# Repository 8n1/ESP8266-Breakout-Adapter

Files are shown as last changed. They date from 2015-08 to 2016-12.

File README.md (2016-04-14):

##ESP-07 & ESP-12 Breakout Adapter

###UPDATE [24.03.2016] - All Breakout Adapters are tested and working as expected. 
####Note: Documentations will be updated and completed within the next days.
<br />
####Version 1.1 - LM1117 (tested)
Used LDO: LM1117
Vin=4.8-15V, Dropout=1.2V, Iq=5mA

oshpark: https://oshpark.com/shared_projects/9CsYq2PY

####Version 2.0A - AS1363 (tested)
Used LDO: AS1363
Vin=3.5-5.5V, Dropout=150mV(-320mV), Iq=40µA

oshpark: https://oshpark.com/shared_projects/2IkxaFPm

####Version 2.0B - SPX3819 (tested)
Used LDO: SPX3819 
Vin=3.7-16V, Dropout=340mV(-550mV), Iq=90µA

oshpark: https://oshpark.com/shared_projects/jsl8ZcFp

####Version 3.1A - AS1363 - Mini (tested)
Used LDO: AS1363
Vin=3.5-5.5V, Dropout=150mV(-320mV), Iq=40µA

oshpark: https://oshpark.com/shared_projects/BgaX81QE

####Version 3.1B - SPX3819 - Mini (tested)
Used LDO: SPX3819 
Vin=3.7-16V, Dropout=340mV(-550mV), Iq=90µA

oshpark: https://oshpark.com/shared_projects/zpDg7761

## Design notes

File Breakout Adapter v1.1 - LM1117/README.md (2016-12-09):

## V1 - 1117 Adapter
<br />

### Changelog/Updates: <br />
V1.1 - Aug, 2015
- Silkscreen optimizations
- Bottom silkscreen moved from layer bNames to bPlace
- Added lables for bottom header
- Smaller gnd vias (0.02755906)

V1.0 - Jun, 2015
- First version

### Pictures
V1.0 - Bare PCB<br />
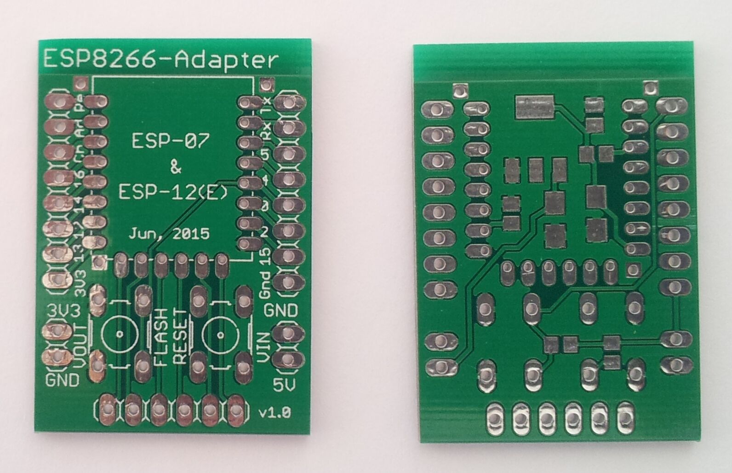
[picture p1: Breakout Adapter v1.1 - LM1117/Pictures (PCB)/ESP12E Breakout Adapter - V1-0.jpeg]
ESP-12 Breakout Adapter V1.0 - Bare PCB

<br />
V1.1 - OSH Park renderings<br />
ESP-12 Breakout Adapter V1.1 - Front&nbsp;
ESP-12 Breakout Adapter V1.1 - Back
<br />
#### Schematic
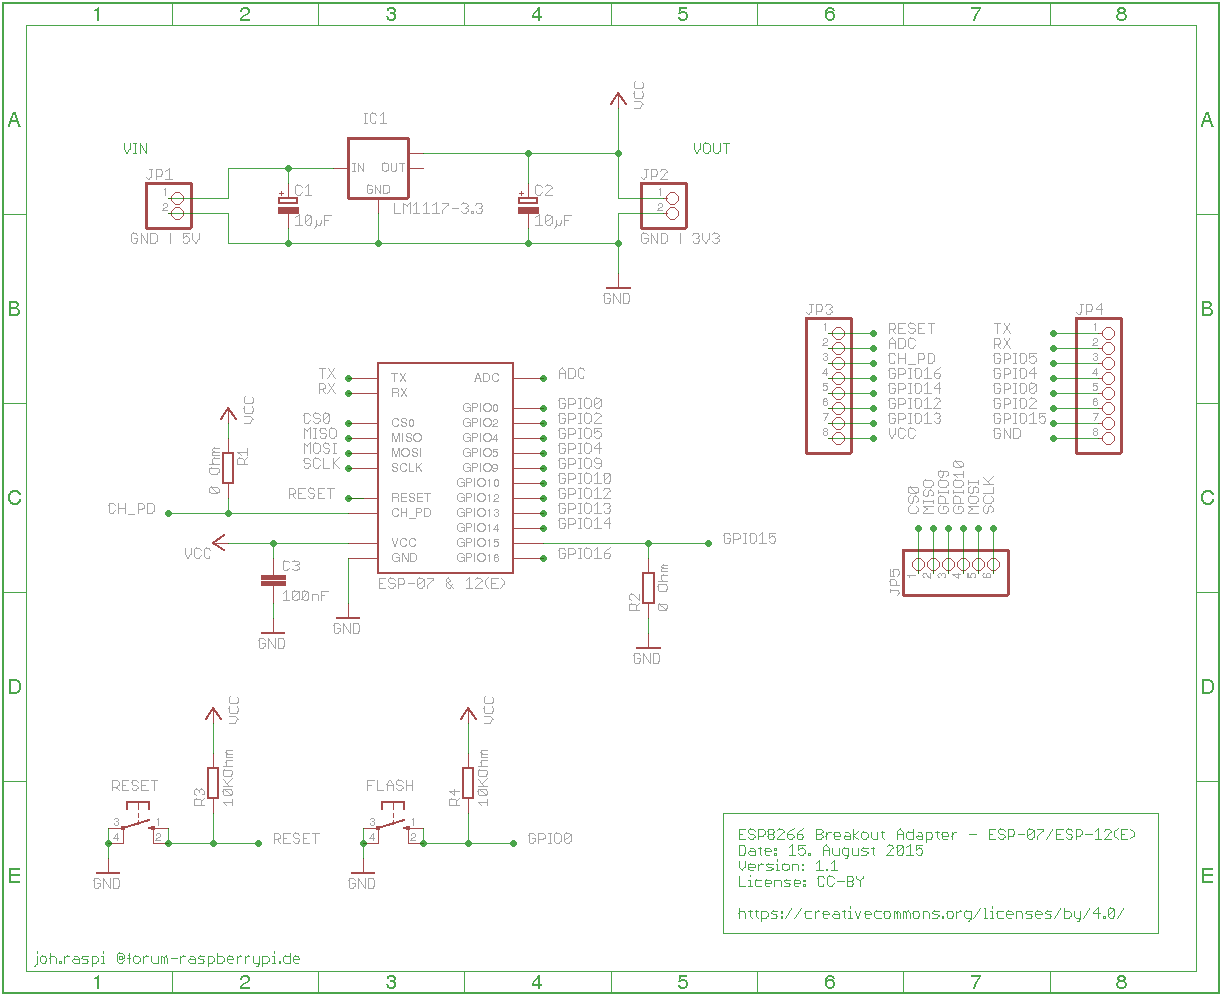
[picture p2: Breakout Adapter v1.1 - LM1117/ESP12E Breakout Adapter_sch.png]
ESP-12 Breakout Adapter V1.1 - Schematic


### Features
* LM1117 Voltage regulator (or pin compatible)
* Flash und Reset switch
* Pullup resistors for Reset, CH_PD and GPIO0
* Pulldown resistor for GPIO15
* ESP-12E bottom header brougth out (see note)
* Breadboard compatible -> One row on both sides stays free
* Except for the headers and switches, fully SMD

##### Note: The additional bottom header on the ESP-12E can not be used without modifying the ESP module:
http://www.esp8266.com/viewtopic.php?f=32&t=4094

### Partlist (v1.1)
| Part  | Value | Info |
|:---|:---|:---|
| IC1 | LM1117 or pincompatible | Voltage regulator |
| C1 | 10µF (Tantalum, Case B) | Input capacitor for IC1 (see the Datasheet)|
| C2 | 10µF (Tantalum, Case B) | Output capacitor for IC1 (see the Datasheet)|
| C3 | 100nF (Ceramic, 0805) | Decoupling capacitor for the ESP module |
| R1 | 10K (0805) * | Pullup resistor for CH_PD |
| R2 | 10K (0805) * | Pulldown resistor for GPIO15 |
| R3 | 10K (0805) | Pullup resistor for Reset |
| R4 | 10K (0805) | Pullup resistor for GPIO0 |
| SW1 | Tactile switch (4pin,6x6,THT) | Flash switch |
| SW2 | Tactile switch (4pin,6x6,THT) | Reset switch |

\* **or** 0Ohm resistor/solderbridge if pin is not needed

Note:  
Pullup and Pulldown resistors(R1, R2, R3, R4) should range from 4.7K to 10K.  
Output capacitor for the voltage regualtor(C2) should be a tantalum type. (See the datasheet)

Pinheader
* 2x 1x8 (2.54mm)
* 2x 1x2 (2.54mm)
* (1x 1x6  (2.54mm)) - "E header"
<br />
Optional "socket" for the esp module
* 2x 1x8 (2mm)
* (1x 1x6 (2mm)) - "E header"

#### Resources:
- LM1117 Datasheet - http://www.ti.com/lit/ds/symlink/lm1117-n.pdf
- AMS1117 Datasheet - http://www.advanced-monolithic.com/pdf/ds1117.pdf

- More Pictures - http://imgur.com/a/fsVE8 (imgur album)

#### This adapter on OSH Park:
- ESP8266 Breakout v1.1 - https://oshpark.com/shared_projects/9CsYq2PY

#### License
<br />
Creative Commons Attribution 4.0 International<br />
http://creativecommons.org/licenses/by/4.0/

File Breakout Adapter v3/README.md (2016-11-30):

## V3 - Mini Adapter

### Changelog/Updates: <br />

V3.1 - Nov, 2015
- Footprint for VREG input and output capacitors changed from 1206 to 0805
- VREG bypass capacitor (C3) removed
- Bigger solderpads for the tactile switches
- Pullup resistor for GPIO2 added (R7)
- Part numbers on bottom side replaced with actual values
- Layout optimized
- Silkscreen fix (description of where the led is connected to was swapped: 3V3<->GPIO13)

V3.0 - Okt, 2015
- First version

### Pictures
V3.1B - OSH Park renderings<br />
ESP-12 Breakout Adapter V1.1 - Front&nbsp;
ESP-12 Breakout Adapter V1.1 - Back
<br />
### Schematic
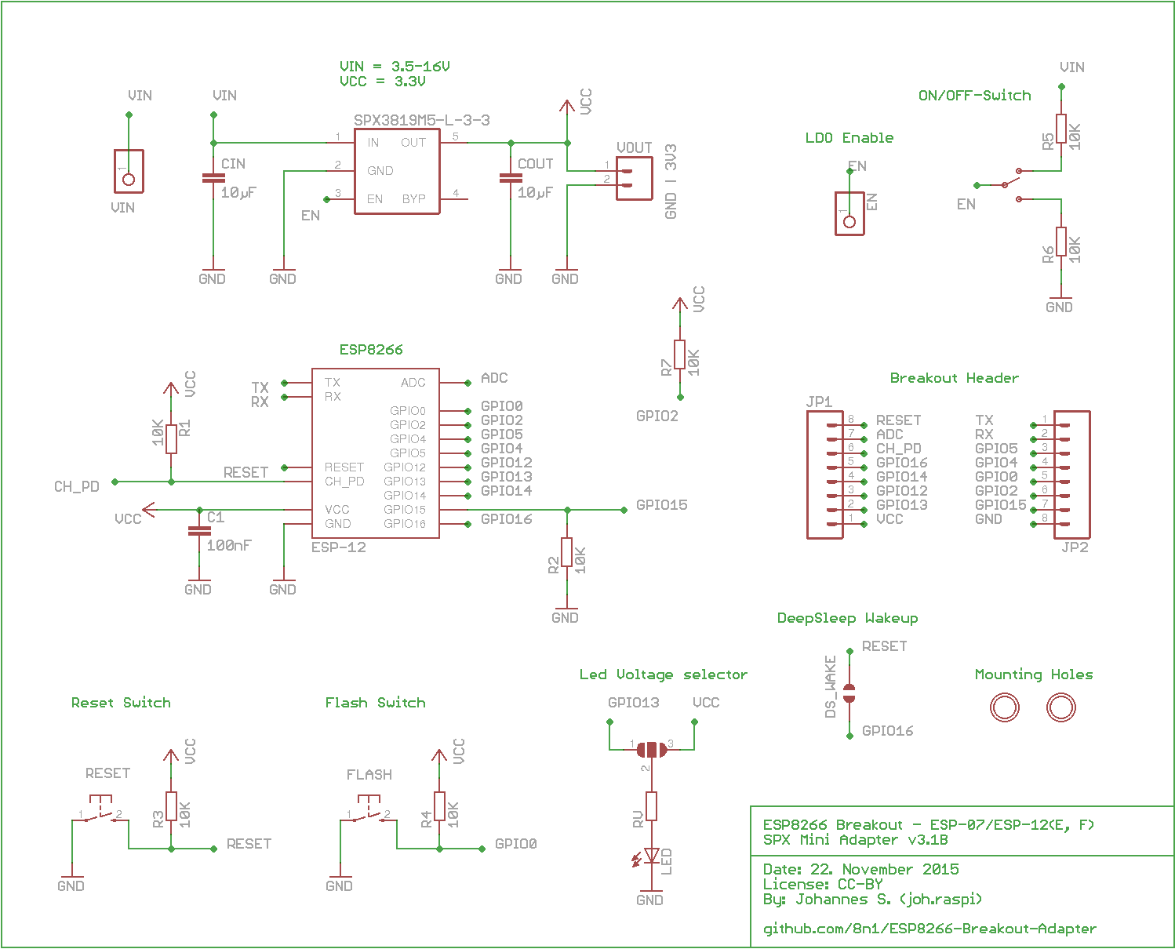
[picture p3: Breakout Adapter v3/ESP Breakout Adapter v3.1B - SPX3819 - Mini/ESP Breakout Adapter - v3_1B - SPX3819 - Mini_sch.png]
ESP-12 Breakout Adapter V3.1 - Schematic


### Features
* ESP-07, ESP-12, ESP-12E and ESP-12F compatible (bottom header for E and F module is not brought out)
* On-board voltage regulator
* Flash and Reset switch
* Pullup resistors for Reset, CH_PD, GPIO0 and GPIO2
* Pulldown resistor for GPIO15
* On/Off Switch *
* LDO Enable Pin brougth out **
* DeepSleep wake-up jumper - Connects Pin8 and Pin32 and allows automatic deep-sleep wake-up
* On-board LED - Anode(+) can either be connected to the LDO ouptut ("3V3") or to "GPIO13" (selected using solderjumper)
* 2 Mountingholes (2.0mm)*)
* Expect for the headers fully SMD
* Breadboard compatible -> 3 rows stay free
* Very small

\* Can be used to completly shutdown the board and everything connected to it. The current consumption in this state will typically be &lt;1µA.  
\** Can be used to externaly turn the board on if the On/Off switch is set to "Off", or off if the On/Off switch is set to "On".

### Partlist (v3.1)
| Part  | Value | Info |
|:---|:---|:---|
| IC1 | AS1363-BSTT-33 (SOT23-6)  | Voltage regulator - Variant "A" |
| IC1 | SPX3819M5-L-3-3 (SOT23-5) | Voltage regulator - Variant "B" |
| C1 | 10µF (Ceramic, 0805) | Input capacitor for the voltage regulator |
| C2 | 10µF (Ceramic, 0805) | Output capacitor for the voltage regulator |
| C3 | 100nF (Ceramic, 0805) | Decoupling capacitor for the ESP module |
| R1 | 10K (0805) * | Pullup resistor for CH_PD |
| R2 | 10K (0805) * | Pulldown resistor for GPIO15 |
| R3 | 10K (0805) | Pullup resistor for Reset |
| R4 | 10K (0805) | Pullup resistor for GPIO0 |
| R7 | 10K (0805) | Pullup resistor for GPIO2 |
| R5 | 10K (0805) | Pullup for LDO enable pin |
| R6 | 10K (0805) | Pulldown for LDO enable pin |
| RV | ~220 Ohm (0805) | [Optional] Current limiting resistor for the led ** |
| LED | LED (0805) ** | [Optional] Led of choice |
| DS | Solderbridge | DeepSleep wake-up jumper |
| FLASH | Tactile Pushbutton SMD 2pin 6x3 | Flash button |
| RESET | Tactile Pushbutton SMD 2pin 6x3 | Reset button |
| On/Off | SMD slide switch (DK: CKN10374CT-ND) (<a href="http://www.ebay.at/itm/20PCS-Mini-Slide-Power-Off-On-Panel-PCB-MINI-SMD-Solder-Switch-SPM-/120731615109">ebay</a>) | On/Off switch |

\* **or** 0Ohm resistor/solderbridge if pin is not needed<br /> 
\** if the led is connected to GPIO13 the led current must be lower then 12mA, calculate the resister value accordingly!

Note:  
Pullup and Pulldown resistors(**R1, R2, R3, R4, R7**)  can range from 4.7K to 10K.  
Pullup and Pulldown resistor for the LDO enable pin(**R5, R6**) should be 10K or higher (100K max).  
Input and output capacitors for the voltage regualtor(**C1, C2**) are LOW ESR ceramic types. (I'm using: SAMSUNG CL21A106KOQNNNG)  

Pinheader
* 2x 1x10 (2.54mm)

Optional "socket" header for the esp module
* 2x 1x8 (2mm) female and male pin header

### Difference between variant A and B
The only difference is the used LDO. Variant A uses the AS1363, variant B the SPX3819(or pincompatible).

#### Resources:
- AS1363 Datasheet - https://ams.com/eng/content/download/1961/15107/file/AS1364_Datasheet_EN_v3.pdf
- SPX3819 Datasheet - https://www.adafruit.com/datasheets/SPX3819_DS_R202_052014.pdf

- More Pictures V3.1 - http://imgur.com/a/jSkG7 (imgur album)
- More Pictures V3.0 - http://imgur.com/a/w46x3 (imgur album)

#### This adapter on OSH Park:
- ESP8266 Breakout v3.1A - https://oshpark.com/shared_projects/RfAN6raq
- ESP8266 Breakout v3.1B - https://oshpark.com/shared_projects/OPku1n9U

#### License
<br />
Creative Commons Attribution 4.0 International<br />
http://creativecommons.org/licenses/by/4.0/

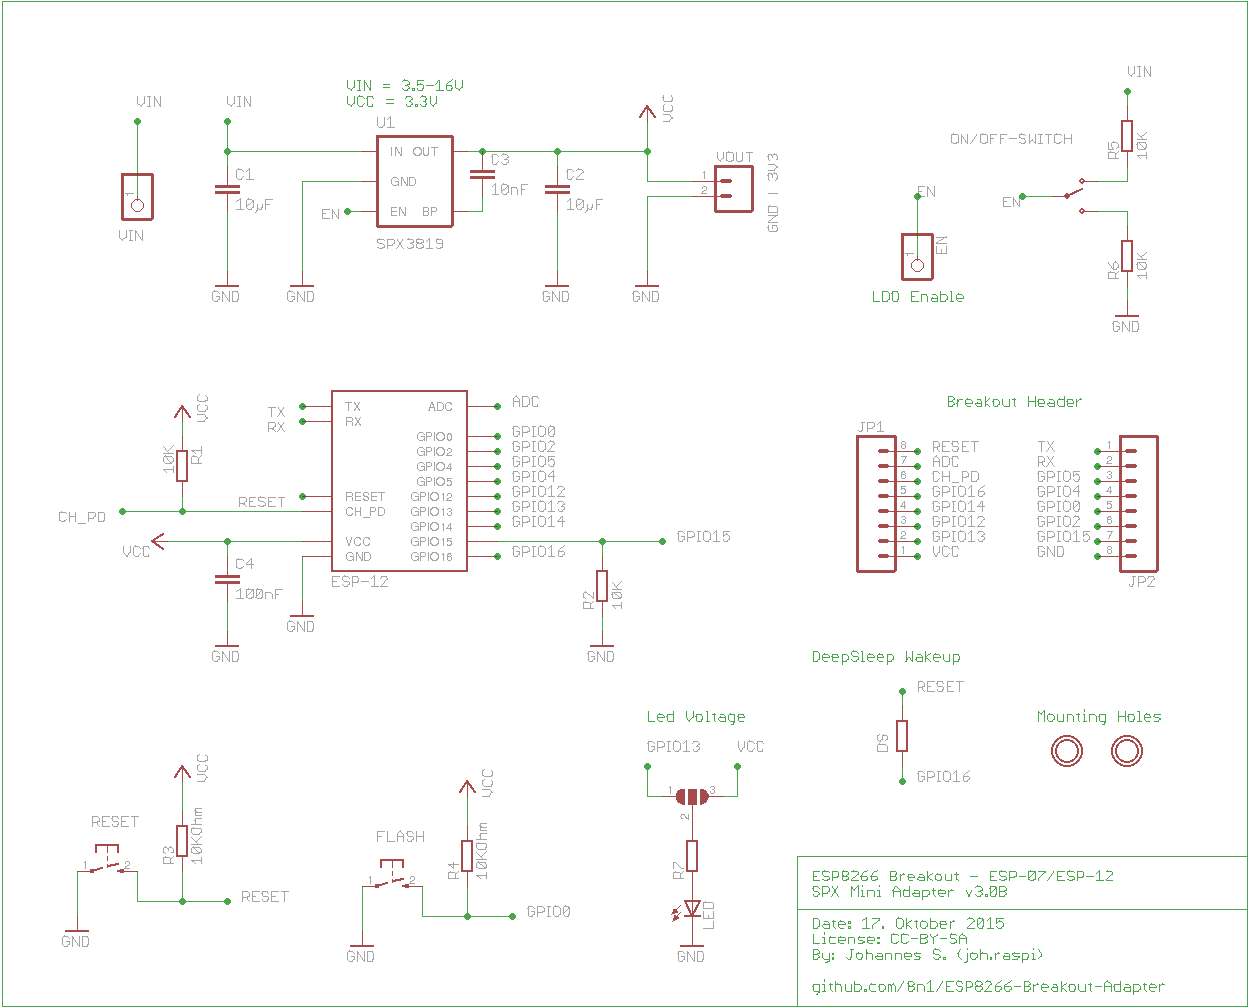
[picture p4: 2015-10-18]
Breakout Adapter v3/ESP Breakout Adapter v3.0B - SPX3819 - Mini/ESP Breakout Adapter - v3_0B - SPX3819 - Mini_sch.png

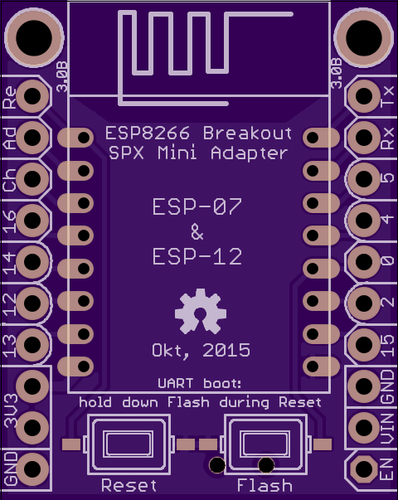
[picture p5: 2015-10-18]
Breakout Adapter v3/ESP Breakout Adapter v3.0B - SPX3819 - Mini/oshpark renderings/oshpark - board top.png

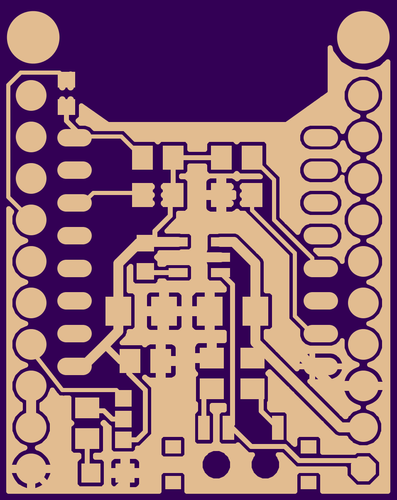
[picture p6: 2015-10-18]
Breakout Adapter v3/ESP Breakout Adapter v3.0B - SPX3819 - Mini/oshpark renderings/oshpark - bottom layer.png

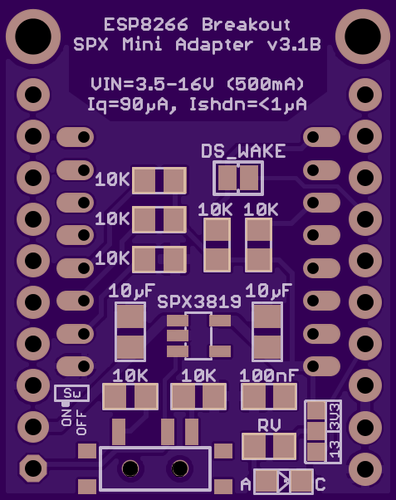
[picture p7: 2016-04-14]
Breakout Adapter v3/ESP Breakout Adapter v3.1B - SPX3819 - Mini/oshpark renderings/Board_Bottom.png

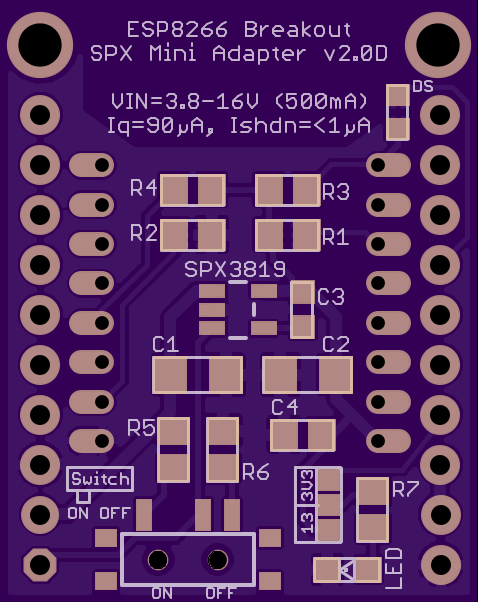
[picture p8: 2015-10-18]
Breakout Adapter v3/ESP Breakout Adapter v3.0B - SPX3819 - Mini/oshpark renderings/b_oshpark - board bottom_b.png

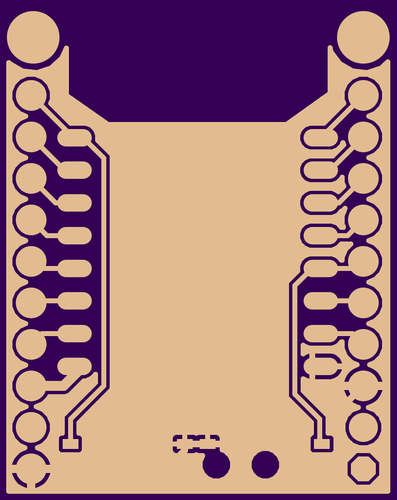
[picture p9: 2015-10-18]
Breakout Adapter v3/ESP Breakout Adapter v3.0A - AS1363 - Mini/oshpark renderings/oshpark - top layer.png

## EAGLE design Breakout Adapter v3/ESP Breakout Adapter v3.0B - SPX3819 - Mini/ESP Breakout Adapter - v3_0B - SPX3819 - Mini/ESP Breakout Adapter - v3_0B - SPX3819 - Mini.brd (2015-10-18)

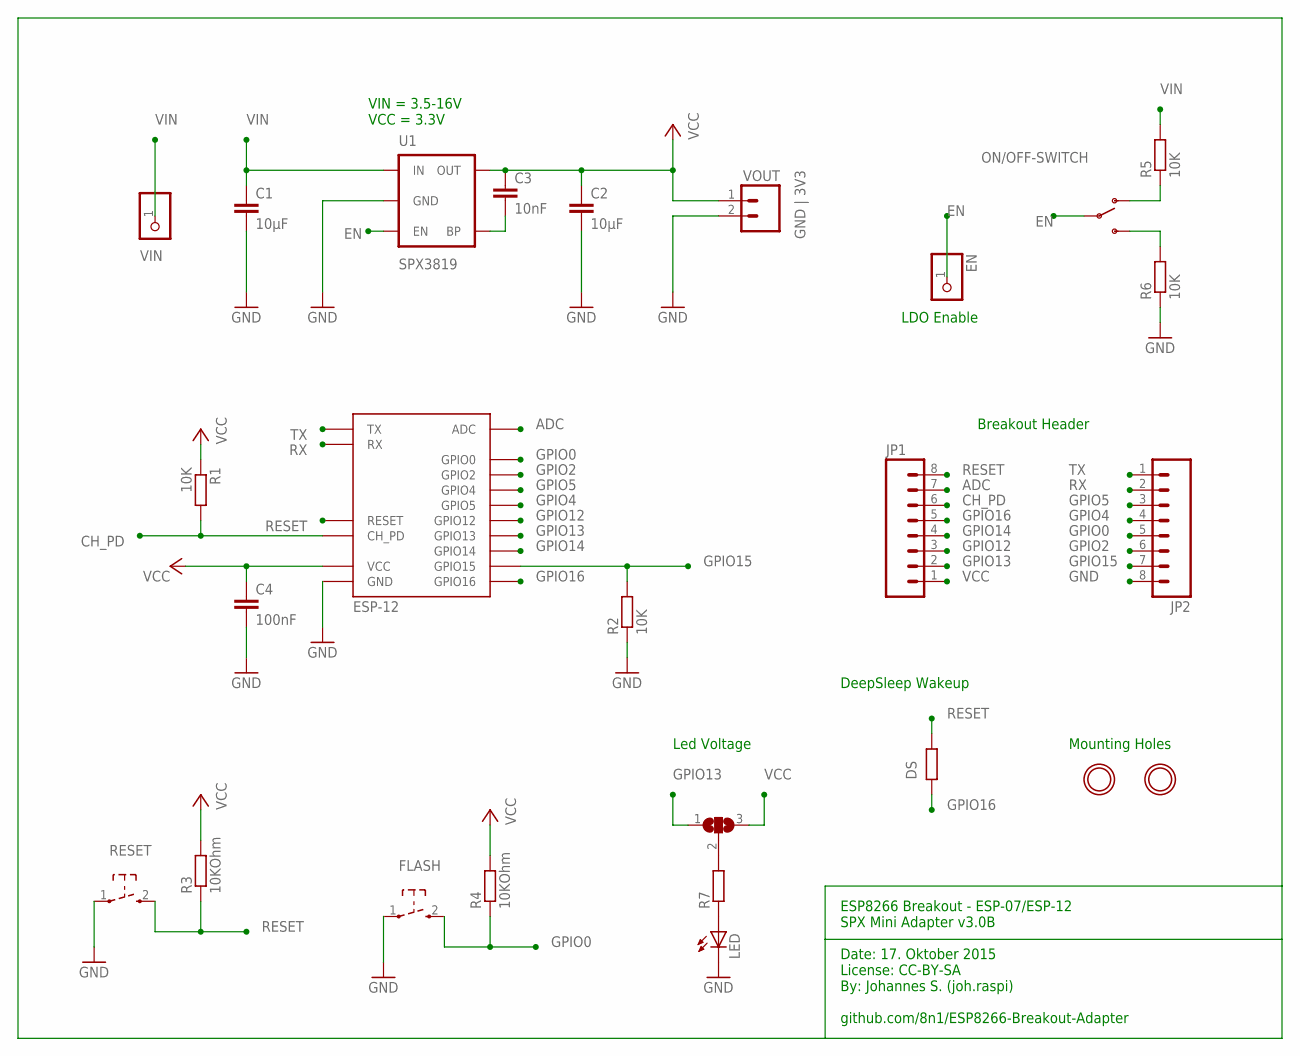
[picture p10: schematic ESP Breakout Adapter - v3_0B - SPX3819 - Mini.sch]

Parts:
C1, C2: 10µF; C1206
C3: 10nF; C0603K
C4: 100nF; C0805
DS: R-EU_R0603; R0603
EN: PINHD-1X1; 1X01
FLASH: SW_TACT_2P-3X6; SW_TACT_3X6
JP1, JP2: M081X08; 1X08
LED: LEDCHIPLED_0805; CHIPLED_0805
LED_VOLTAGE: SJ2W; SJ_2
ON/OFF-SWITCH: SWITCH_SPDT; KPS-1290
R1, R2, R5, R6: 10K; R0805
R3, R4: 10KOhm; R0805
R7: R-EU_R0805; R0805
RESET: SW_TACT_2P-3X6; SW_TACT_3X6
U1: SPX3819; SOT23-5
U$1: ESP-12
U$4, U$5: MOUNTINGHOLE2.0; MOUNTINGHOLE_2.0_PLATED
VIN: M01PTH_2MM; 1X01-CLEANBIG
VOUT: GND | 3V3; 1X02

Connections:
123: ON/OFF-SWITCH.S, R6.2
ADC: JP1.7, U$1.ADC
CH_PD: JP1.6, R1.2, U$1.CH_PD
EN: EN.1, ON/OFF-SWITCH.P, U1.3 (EN)
GND: C1.2, C2.2, C4.2, FLASH.1, JP2.8, LED.C, R2.1, R6.1, RESET.1, U1.2 (GND), U$1.GND, VOUT.2
GPIO0: FLASH.2 (3), JP2.5, R4.1, U$1.GPIO0
GPIO2: JP2.6, U$1.GPIO2
GPIO4: JP2.4, U$1.GPIO5
GPIO5: JP2.3, U$1.GPIO4
GPIO12: JP1.3, U$1.GPIO12
GPIO13: JP1.2, LED_VOLTAGE.1, U$1.GPIO13
GPIO14: JP1.4, U$1.GPIO14
GPIO15: JP2.7, R2.2, U$1.GPIO15
GPIO16: DS.1, JP1.5, U$1.GPIO16
unnamed: LED_VOLTAGE.2, R7.2
unnamed: ON/OFF-SWITCH.O, R5.1
unnamed: LED.A, R7.1
RESET: DS.2, JP1.8, R3.1, RESET.2 (3), U$1.RESET
RX: JP2.2, U$1.RX
SET/BYP: C3.2, U1.4 (BP)
TX: JP2.1, U$1.TX
VCC: C2.1, C3.1, C4.1, JP1.1, LED_VOLTAGE.3, R1.1, R3.2, R4.2, U1.5 (OUT), U$1.VCC, VOUT.1
VIN: C1.1, R5.2, U1.1 (IN), VIN.1

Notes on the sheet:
ESP8266 Breakout - ESP-07/ESP-12 SPX Mini Adapter v3.0B Date: 17. Oktober 2015 License: CC-BY-SA By: Johannes S. (joh.raspi) github.com/8n1/ESP8266-Breakout-Adapter
Mounting Holes
DeepSleep Wakeup
Breakout Header
VIN = 3.5-16V VCC = 3.3V
Led Voltage
LDO Enable

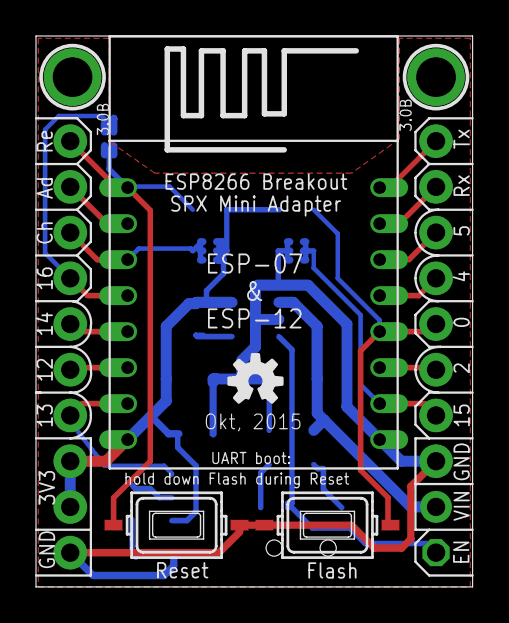
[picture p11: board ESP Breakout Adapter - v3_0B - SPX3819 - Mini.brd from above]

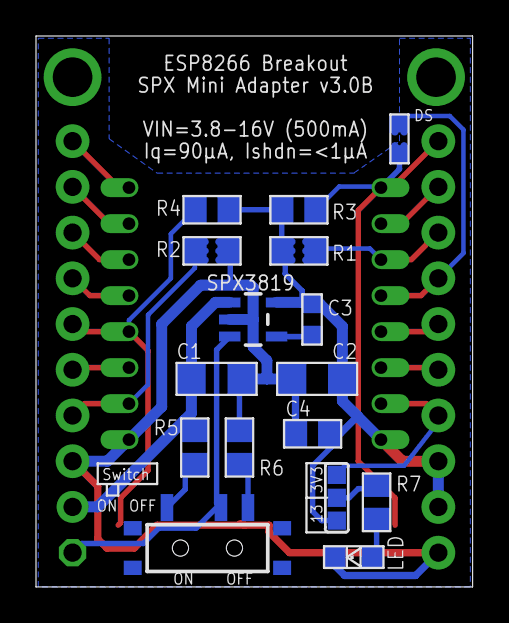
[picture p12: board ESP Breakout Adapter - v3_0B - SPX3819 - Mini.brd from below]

Board: 2 copper layers, 24.3 x 30.6 mm, 27 parts (16 on the bottom side), 23 nets.

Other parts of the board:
U$2: OSHW-LOGO-S

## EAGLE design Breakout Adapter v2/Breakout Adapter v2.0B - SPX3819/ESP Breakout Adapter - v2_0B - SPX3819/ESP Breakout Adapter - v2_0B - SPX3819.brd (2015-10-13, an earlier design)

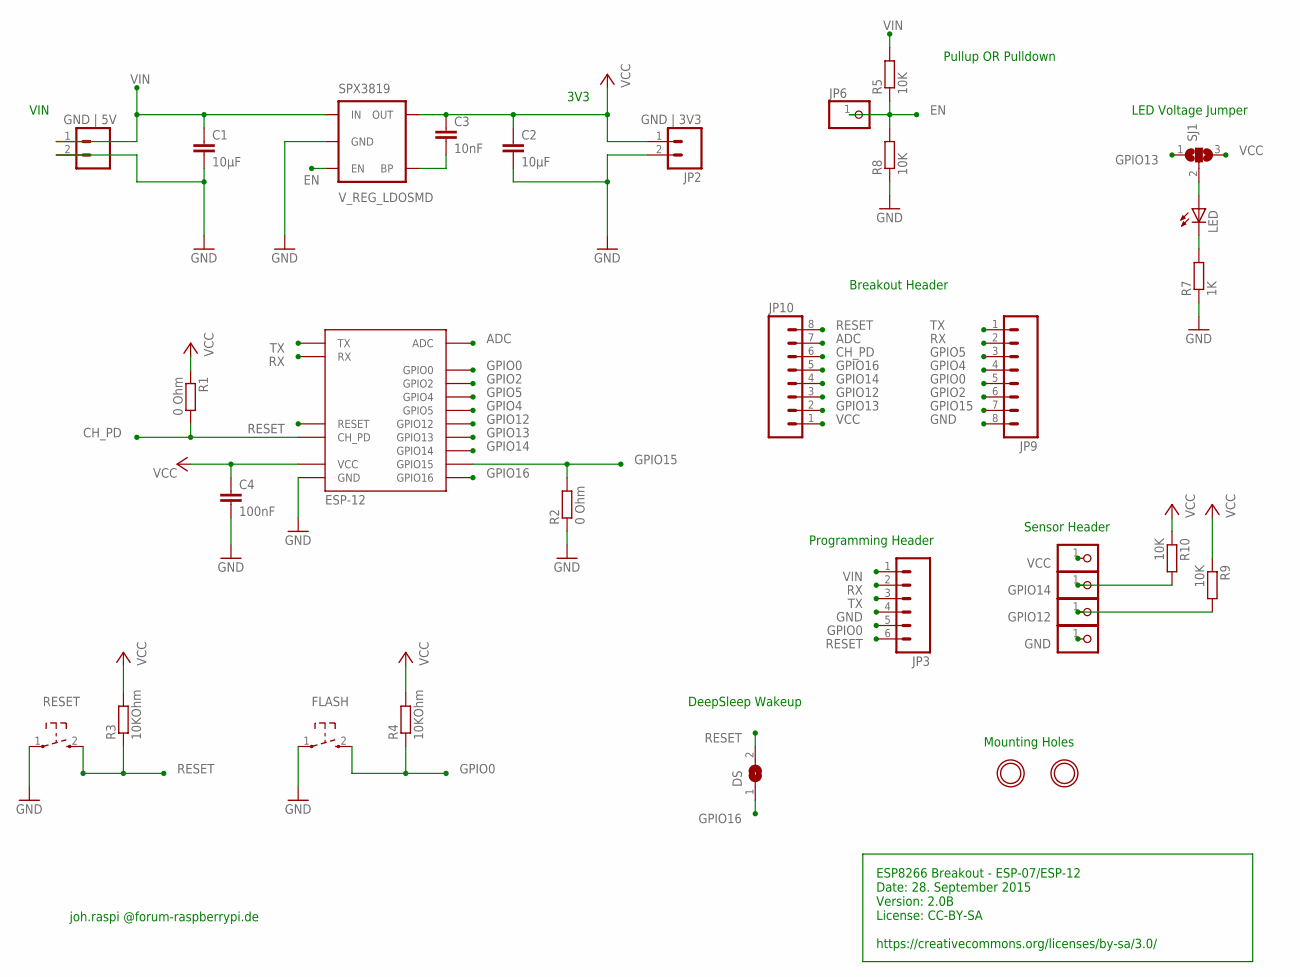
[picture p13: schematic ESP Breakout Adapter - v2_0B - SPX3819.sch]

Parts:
C1, C2: 10µF; C1206
C3: 10nF; C0603K
C4: 100nF; C0805
DS: SJ
FLASH: SW_TACT_2P-3X6; SW_TACT_3X6
JP1: GND | 5V; 1X02
JP2: GND | 3V3; 1X02
JP3: M06SIP; 1X06
JP4, JP6, JP7, JP8, JP11: PINHD-1X1; 1X01
JP9, JP10: M081X08; 1X08
LED: LED-0805; LED-805
R1, R2: 0 Ohm; R0805
R3, R4: 10KOhm; R0805
R5, R8, R9, R10: 10K; R0805
R7: 1K; R0805
RESET: SW_TACT_2P-3X6; SW_TACT_3X6
SJ1: SJ2W; SJ_2
SPX3819: V_REG_LDOSMD; SOT23-5
U$1: ESP-12
U$4, U$5: MOUNTINGHOLE2.0; MOUNTINGHOLE_2.0_PLATED

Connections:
ADC: JP10.7, U$1.ADC
CH_PD: JP10.6, R1.2, U$1.CH_PD
EN: JP6.1, R5.1, R8.2, SPX3819.3 (EN)
GND: C1.2, C2.2, C4.2, FLASH.1, JP1.2, JP2.2, JP3.4, JP4.1, JP9.8, R2.1, R7.1, R8.1, RESET.1, SPX3819.2 (GND), U$1.GND
GPIO0: FLASH.2 (3), JP3.5, JP9.5, R4.1, U$1.GPIO0
GPIO2: JP9.6, U$1.GPIO2
GPIO4: JP9.4, U$1.GPIO5
GPIO5: JP9.3, U$1.GPIO4
GPIO12: JP7.1, JP10.3, R9.2, U$1.GPIO12
GPIO13: JP10.2, SJ1.1, U$1.GPIO13
GPIO14: JP10.4, JP11.1, R10.2, U$1.GPIO14
GPIO15: JP9.7, R2.2, U$1.GPIO15
GPIO16: DS.1, JP10.5, U$1.GPIO16
unnamed: LED.C, R7.2
unnamed: LED.A, SJ1.2
RESET: DS.2, JP3.6, JP10.8, R3.1, RESET.2 (3), U$1.RESET
RX: JP3.2, JP9.2, U$1.RX
SET/BYP: C3.2, SPX3819.4 (BP)
TX: JP3.3, JP9.1, U$1.TX
VCC: C2.1, C3.1, C4.1, JP2.1, JP8.1, JP10.1, R1.1, R3.2, R4.2, R9.1, R10.1, SJ1.3, SPX3819.5 (OUT), U$1.VCC
VIN: C1.1, JP1.1, JP3.1, R5.2, SPX3819.1 (IN)

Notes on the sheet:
VIN
3V3
ESP8266 Breakout - ESP-07/ESP-12 Date: 28. September 2015 Version: 2.0B License: CC-BY-SA https://creativecommons.org/licenses/by-sa/3.0/
joh.raspi @forum-raspberrypi.de
Mounting Holes
Pullup OR Pulldown
DeepSleep Wakeup
Programming Header
Sensor Header
Breakout Header
LED Voltage Jumper

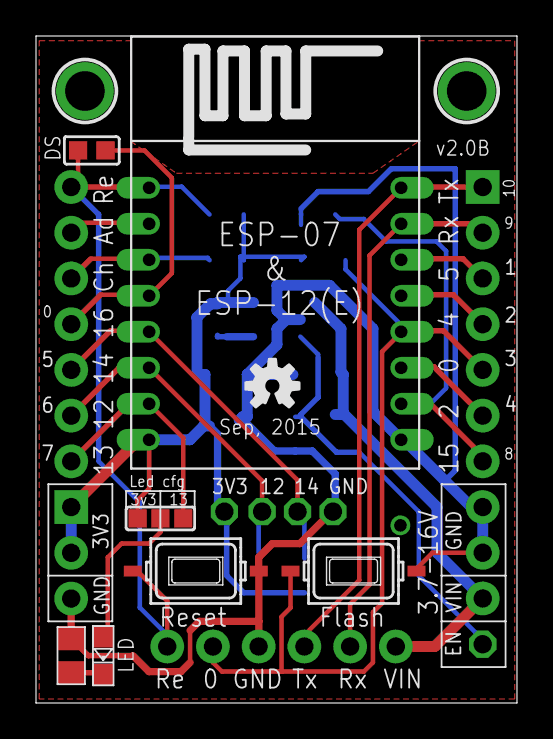
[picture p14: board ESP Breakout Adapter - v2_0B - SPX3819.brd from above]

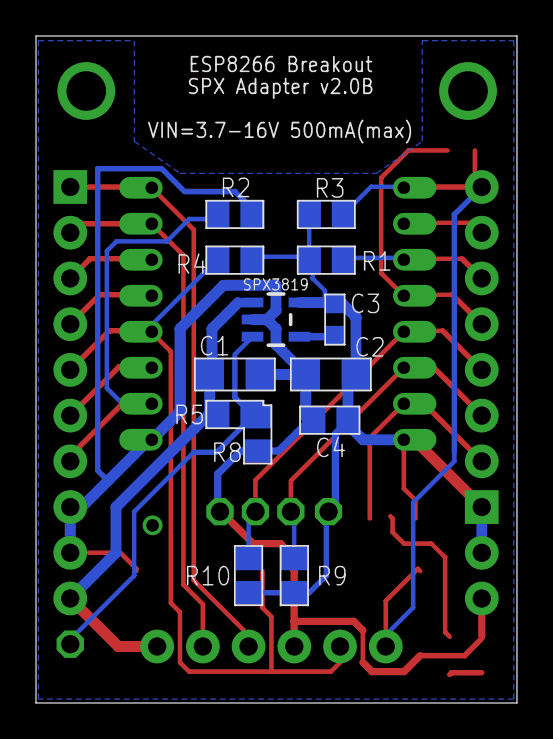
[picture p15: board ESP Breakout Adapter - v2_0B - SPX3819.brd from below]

Board: 2 copper layers, 26.7 x 37.1 mm, 33 parts (13 on the bottom side), 21 nets.

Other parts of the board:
U$3: OSHW-LOGO-S

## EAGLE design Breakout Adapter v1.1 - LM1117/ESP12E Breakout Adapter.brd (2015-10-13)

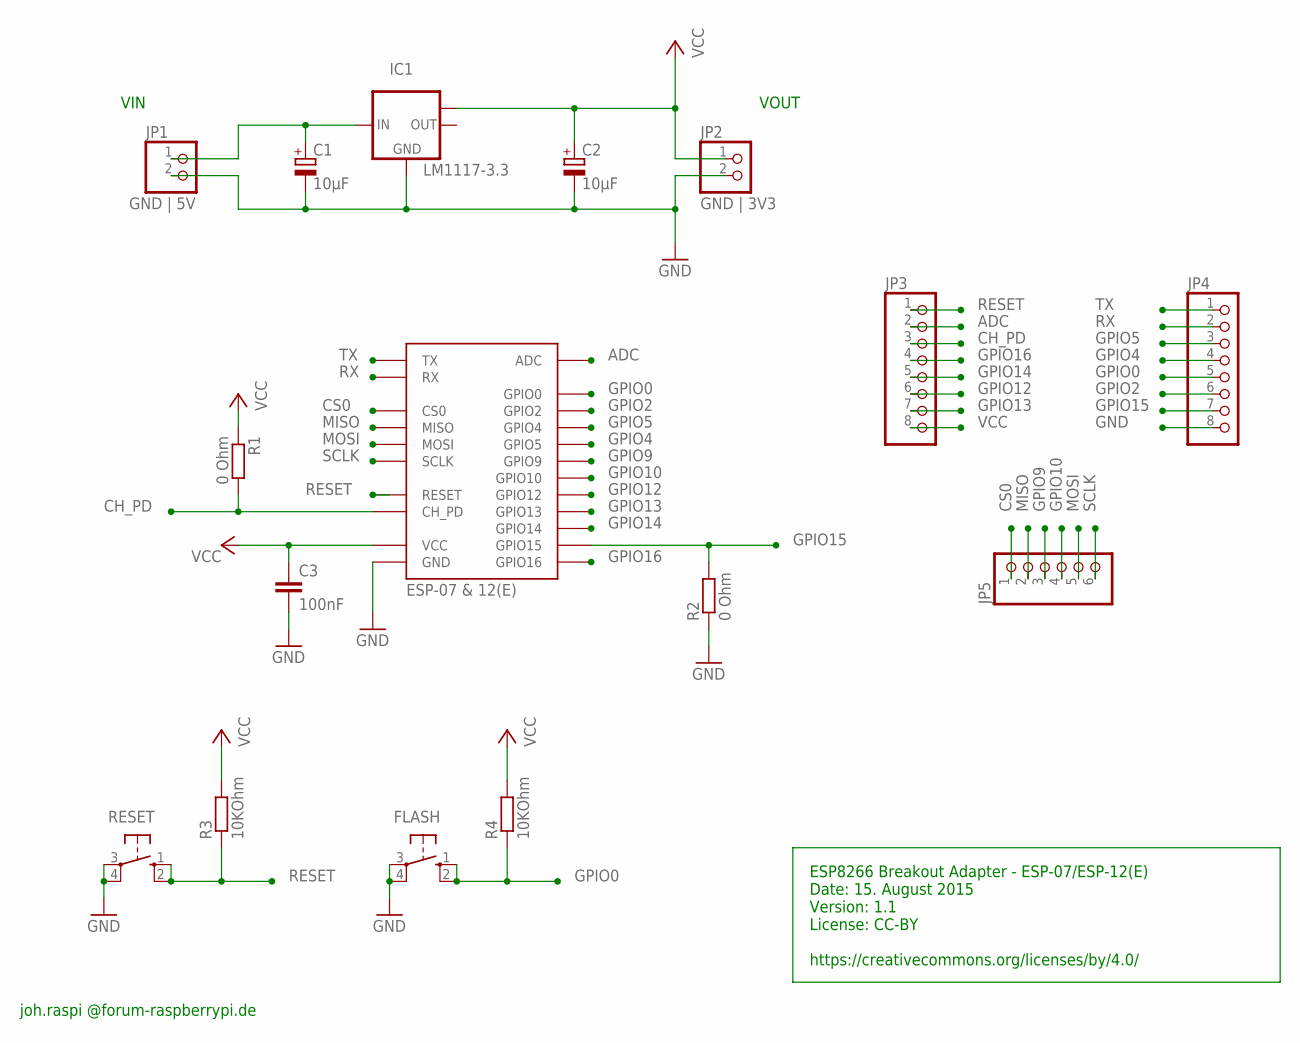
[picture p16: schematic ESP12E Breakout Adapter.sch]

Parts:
C1, C2: 10µF; B/3528-21W
C3: 100nF; C0805K
ESP8266: ESP-07 & 12(E); ESP-12-E
FLASH_SWITCH: FLASH; B3F-10XX
IC1: LM1117-3.3; SOT223
JP1: GND | 5V; 1X02
JP2: GND | 3V3; 1X02
JP3, JP4: PINHD-1X8; 1X08
JP5: PINHD-1X6; 1X06
R1, R2: 0 Ohm; R0805
R3, R4: 10KOhm; R0805
RESET_SWITCH: RESET; B3F-10XX

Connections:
ADC: ESP8266.ADC, JP3.2
CH_PD: ESP8266.CH_PD, JP3.3, R1.2
CS0: ESP8266.CS0, JP5.1
GND: C1.-, C2.-, C3.2, ESP8266.GND, FLASH_SWITCH.3, FLASH_SWITCH.4 (P1), IC1.1 (GND), JP1.2, JP2.2, JP4.8, R2.1, RESET_SWITCH.3, RESET_SWITCH.4 (P1)
GPIO0: ESP8266.GPIO0, FLASH_SWITCH.1 (S), FLASH_SWITCH.2 (S1), JP4.5, R4.1
GPIO2: ESP8266.GPIO2, JP4.6
GPIO4: ESP8266.GPIO5, JP4.4
GPIO5: ESP8266.GPIO4, JP4.3
GPIO9: ESP8266.GPIO9, JP5.3
GPIO10: ESP8266.GPIO10, JP5.4
GPIO12: ESP8266.GPIO12, JP3.6
GPIO13: ESP8266.GPIO13, JP3.7
GPIO14: ESP8266.GPIO14, JP3.5
GPIO15: ESP8266.GPIO15, JP4.7, R2.2
GPIO16: ESP8266.GPIO16, JP3.4
MISO: ESP8266.MISO, JP5.2
MOSI: ESP8266.MOSI, JP5.5
RESET: ESP8266.RESET, JP3.1, R3.1, RESET_SWITCH.1 (S), RESET_SWITCH.2 (S1)
RX: ESP8266.RX, JP4.2
SCLK: ESP8266.SCLK, JP5.6
TX: ESP8266.TX, JP4.1
VCC: C2.+, C3.1, ESP8266.VCC, IC1.TAB (OUT1), JP2.1, JP3.8, R1.1, R3.2, R4.2
VIN: C1.+, IC1.3 (IN), JP1.1

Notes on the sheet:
VIN
VOUT
ESP8266 Breakout Adapter - ESP-07/ESP-12(E) Date: 15. August 2015 Version: 1.1 License: CC-BY https://creativecommons.org/licenses/by/4.0/
joh.raspi @forum-raspberrypi.de

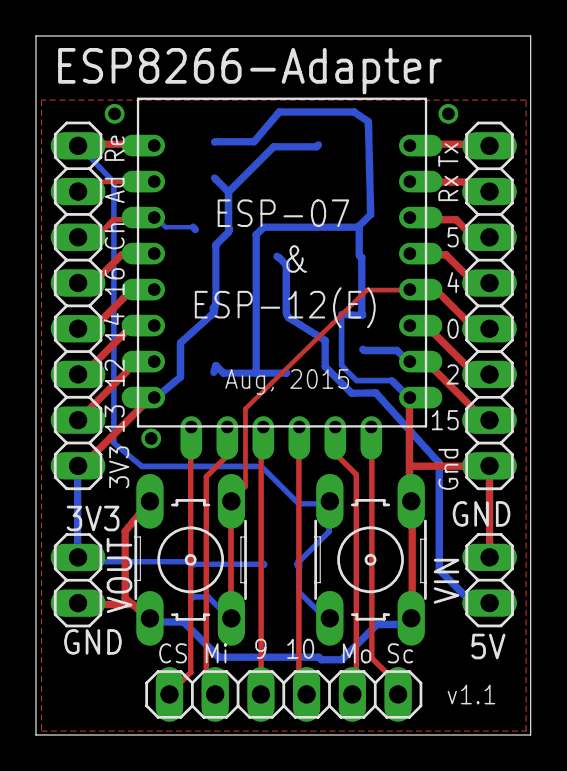
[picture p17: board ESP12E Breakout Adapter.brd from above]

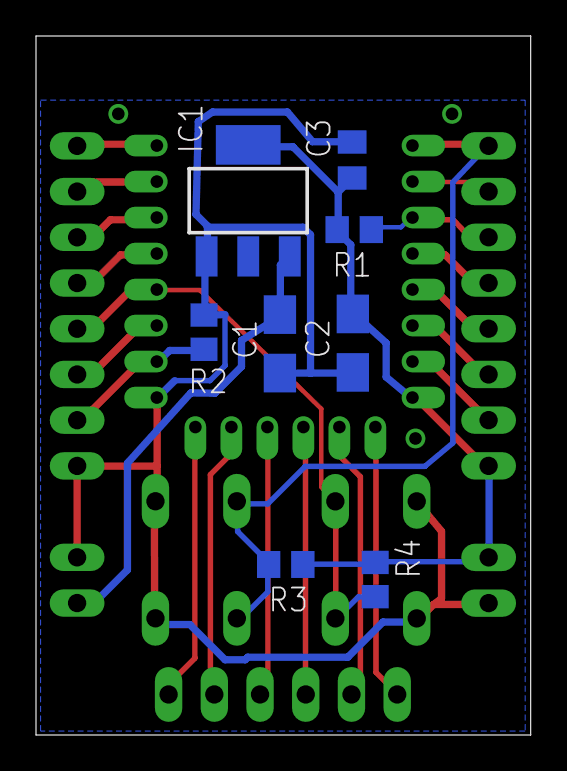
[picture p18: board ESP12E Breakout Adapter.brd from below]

Board: 2 copper layers, 27.5 x 38.8 mm, 16 parts (8 on the bottom side), 23 nets.

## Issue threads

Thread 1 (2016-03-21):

Upload BOM excel.

Saxin, 2016-03-21:
Hi,

Possible from your side to upload BOM excel for the boards ?

thanks, Eddi

8n1, 2016-03-24:
Hi,
Documentations including BOM(Partlist) will be updated within the next days.

John

Saxin, 2016-03-24:
Thanks a lot.

yannickgagne, 2016-03-29:
hey dude, just wanted to know if the BOM located here is the right one?

https://github.com/8n1/ESP8266-Breakout-Adapter/tree/master/Breakout%20Adapter%20v1.1%20-%20LM1117

And your work is awesome, thanks for sharing!!!

8n1, 2016-03-31:
Hi,
I've actually made 3 different versions but only version 1 (the one you've linked to) is really documented rigth now.
Docs for version 2 and 3 will probably follow tomorrow.

I just managed to take some pictures of all 3 versions:
Version 1: http://imgur.com/a/fsVE8
Version 2: http://imgur.com/a/XCGv0
Version 3: http://imgur.com/a/jSkG7

yannickgagne, 2016-03-31:
Ok great!

I already ordered v1.1 and v3.0A from OSH Park, can't wait to order the parts and try them out.

Thanks again for your work.

yannickgagne, 2016-04-14:
Hi,

just saw your update this morning and I just need your help for 2 components.

I would need to know the size of tact switch for the "ESP8266 Breakout v1.1 - x1117" board.

And what size is the slide switch used on "ESP Breakout Adapter v3.1A - AS1363 - Mini" board.

Thanks a lot!

8n1, 2016-04-14:
The used tact switch is a standard sized(6x6) one like this:
http://www.ebay.at/itm/100Pcs-Tactile-Push-Button-Switch-Tact-Switch-6X6X5mm-4-pin-DIP-NEW-/181846910852
But you could also use one with just two pins like I did (the blue one on the pictures).

The slide switch I used is exactly this one:
www.ebay.at/itm/20PCS-Mini-Slide-Power-Off-On-Panel-PCB-MINI-SMD-Solder-Switch-SPM-/120731615109
I'm not sure about the exact part number but if you search for "mini slide switch smd" on ebay you'll find a lot of similar ones.

If you have any further questions feel free to ask.

yannickgagne, 2016-04-20:
Got some parts from Digikey today and wanted to let you know that the following slide switch fits perfectly if you want to add it to your BOM.

http://www.digikey.ca/product-search/en?keywords=CKN10374CT-ND

8n1, 2016-04-20:
Hey, thanks for the info! I will add it.

yannickgagne, 2016-04-26:
Just wanted to let you know that I built a v1.1 last week and it works perfectly.

Will try the v3.1A soon.

Closed 2017-05-09.

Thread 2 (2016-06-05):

assembly?

jlippa, 2016-06-05:
Fabulous work well done. Just one question really - are you able to say where it is that you're getting these boards assembled / soldered with the components listed in the BOM?

yannickgagne, 2016-06-06:
I got the board from oshpark.com and the parts from digikey.com

jlippa, 2016-06-06:
It sounds like you're assembling and soldering all components on yourself. Is that right?

yannickgagne, 2016-06-06:
yes

Closed 2016-06-06.

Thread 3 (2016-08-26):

Eagle file downloads

REHolt, 2016-08-26:
Hi, I was wanting to download your Eagle CAD files to take a look at your circuit. I want to expand on this and build a couple of special purpose boards for the ESP12E that I bought. However, when I download the  files and try to open them in Eagle CAD, I get an error saying they are not eagle files. I am using Eagle ver 7.6.0 (the latest version). yours appear to be 7.4 so they should be compatible. Anything special I need to do to download them?

REHolt, 2016-08-27:
I found a solution. I opened the file on the github page, in RAW format, I then saved it to my project directory. For some reason Eagle was able to read it that way even though directly saving the file didn't work.

My question now is about the bottom row of pins on the ESP12E. On the board layout they are there, but in the symbol they are not. I assume you manually placed pads for this row? I asked because I have not been able to find a proper board symbol for the part. Since I am currently less than half way up the learning curve for Eagle cad, I didn't want to attempt making this symbol myself:)

REHolt, 2016-08-27:
Sorry, I'm just blind. I downloaded the wrong version. 1.1 has the correct pad layout.

Closed 2017-05-09.

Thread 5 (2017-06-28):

spx board connection is wrong

curlyz, 2017-06-28:
i tried spx3819 with 10K resistor already , doesnt work , mainly because 10K will make it impossible to put enough current to EN , there should not be a resistor between VCC and EN.

Figure it out with pain.

THIS IS PERSONAL EXPERIENCE , NOT CONFIRMED BY EXPERT.

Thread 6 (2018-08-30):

AutoCAD Eagle -

al-ang, 2018-08-30:
I opened your project ESP Breakout Adapter v3.1B - SPX3819 - Mini  in AutoCAD Eagle and noticed a warning "There are still airwires left".  I'm new to the program and I am admittedly overwhelmed with Eagle so it's taking me forever to see what's causing the message.  Do you know, and if so, is this a minor warning that can be ignored?

Your design rocks BTW.  I only have one suggestion -- to add through holes for flash;  I might like to add a wire to a button for flashing so when I embed this in a housing I can place a flash button someplace that's accessible (when the pcb board is buried in a device).

So far that change might be above my pay grade since it looks like the Eagle learning curve is pretty steep.  Regardless, I really like your design.  Please let us know if you've made any further improvements.

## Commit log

2015-08-17 version 1.1
    [ESP12E Breakout Adapter.brd, ESP12E Breakout Adapter.sch]
2015-10-13 update version 2
    [ESP Breakout Adapter - v2_0A - AS1363.brd, ESP Breakout Adapter - v2_0A - AS1363.sch, ESP Breakout Adapter - v2_0B - SPX3819.brd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]
2015-10-13 kleine änderung
    [ESP12E Breakout Adapter.brd, ESP12E Breakout Adapter.sch]
2015-10-16 mini adapter
    [ESP Breakout Adapter - v2_0A - AS1363 - Mini.brd, ESP Breakout Adapter - v2_0A - AS1363 - Mini.sch, ESP Breakout Adapter - v2_0A - AS1363.brd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]
2015-10-18 mini änderung
    [ESP Breakout Adapter - v2_0A - AS1363 - Mini.brd, ESP Breakout Adapter - v2_0A - AS1363 - Mini.sch, ESP Breakout Adapter - v2_0D - SPX3819 - Mini.brd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]
2015-10-18 neue versionierung
    [ESP Breakout Adapter - v3_0A - AS1363 - Mini.brd, ESP Breakout Adapter - v3_0A - AS1363 - Mini.sch, ESP Breakout Adapter - v3_0B - SPX3819 - Mini.brd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]
2016-04-14 updated docs, new version(3.1)
    [ESP Breakout Adapter - v2_0A - AS1363.brd, ESP Breakout Adapter - v2_0A - AS1363.sch, ESP Breakout Adapter - v2_0B - SPX3819.brd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]
2016-04-20 added digikey slide switch part number add
2016-04-20 digikey slide switch part number added

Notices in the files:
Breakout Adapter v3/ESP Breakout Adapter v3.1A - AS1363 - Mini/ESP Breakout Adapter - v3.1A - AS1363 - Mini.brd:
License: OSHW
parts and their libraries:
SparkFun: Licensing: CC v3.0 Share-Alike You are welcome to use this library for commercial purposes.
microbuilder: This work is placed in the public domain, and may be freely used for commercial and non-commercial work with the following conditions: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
